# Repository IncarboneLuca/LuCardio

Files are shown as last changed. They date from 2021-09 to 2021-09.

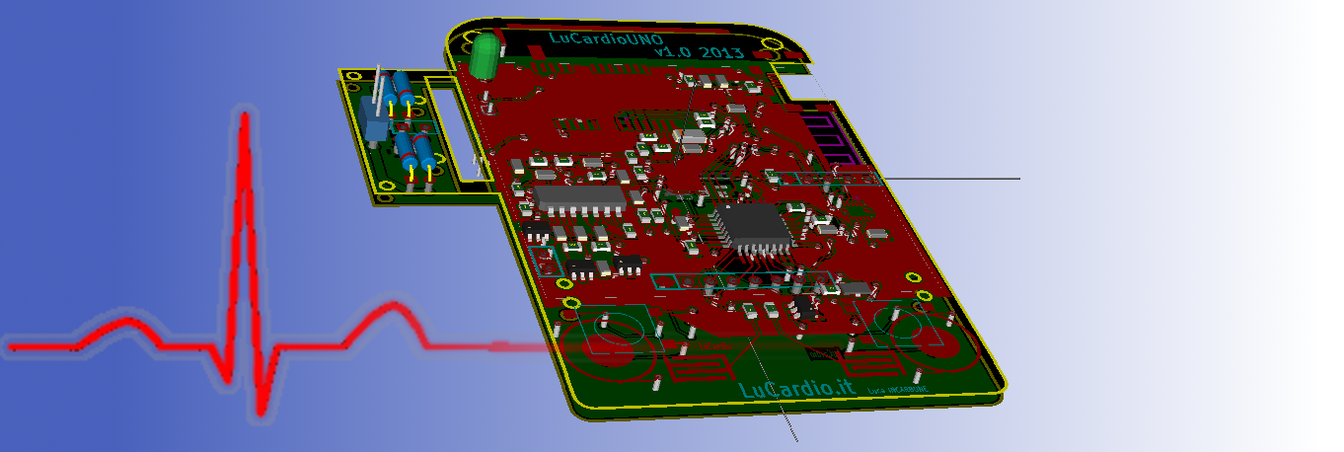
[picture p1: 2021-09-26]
sch/LuCardio_6.png

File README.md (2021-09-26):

# LuCardio
Project started in 2013 with goal to develop a connected SportWatch.
Project phases:
  -Develop the analogic circuit to amplify and filter ECG body signal
  -Analogic interface with the bike to measure the speed
  -PCB layout capacitive button to detect the finger (touch button instead of pushbutton)
  -Develop the Arduino code to test in field and improve the algorithm
  -Develop a second version to run the code on a specific PCB designed (that also include a GNSS receiver and a PCB designed antenna)

Unfortunately the second version was never end because the GNSS receiver chosen had major problem with I2C communication and never work properly. Time and cost to make a second PCB and chose a second GNSS receiver made stop the project

The prototype with ArduinoUNO board was finished, used and tested.

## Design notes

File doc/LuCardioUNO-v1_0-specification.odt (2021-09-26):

# LuCardioUNO v1.0 Specification


# High level Fonctional Specifications

Tag | Specification | min | Typ | Max
1 | GENERAL SPECIFICATION
1.0 | Turn on time in recording mode | 5h | 8h | 10h
1.0.1 | Current consumption in recording mode | | | 150mA
1.0.2 | Battery capacity | 750mA/h | 1500mA/h | -
1.1 | Time to full recharge | | 1h | 3h
1.2 | Fonctional Temperature Range | -10° | - | 40°
1.3 | Backlight duration | | 3 sec
1.4 | Graphic LCD with back-light | LCD NOKIA 5510
1.5 | GPS Antenna (1.575 GHz) | Integrated on PCB
1.6 | Data Connectivity | Bluetooth
1.7 | Power Supply | USB Micro B
2 | ELECTRICAL SPECIFICATION
2.0.0 | Charging voltage | 4.7V | 5V | 6.2V
2.0.1 | Charging current | - | - | 1A
2.1 | System voltage | | 3.3V
3 | PERFORMANCE SPECIFICATION
3.0.0 | Heart Rate Range | 20bpm | - | 220bpm
3.0.1 | Bike Speed Range | 1km/h | - | 100km/h
3.0.2 | Pedal Rate Range | 20 r/min | - | 200 r/min
3.1.1 | Refresh Data Temperature | - | 1 ref/s | -
3.1.2 | Recording Rate | - | 1 rec/s | -
3.1.3 | Refresh LCD output | - | 1 ref/s | -
4 | MECANICAL SPECIFICATION
4.1 | Touch button | | 2
4.2 | Size of PCB (2 Layers) | Battery Size
4.3 | Standard plug I/O (idiot-proof)
4.3.1 | Charging/Pedal/Weel | USB Micro B
4.3.2 | ECG contacts | DX female
4.4.0 | Water proof
5 | HUMAN INTERFACE
5.0 | Menu interactive
5.1 | Screen data
5.2 | Android interface (via Bluetooth)

# LCD data screen specification

## Welcome screen

To be defined

## Recording/Running Mode

Tag | Specification | min | Max | Unit
6.0 | Recording Screen
6.0.0 | Distance measure | 0 | 10'000 | m
| | 10 | 999 | km
6.0.1 | Total distance measure | 0 | 9999999 | km
6.0.2 | Speed bike | 1 | 100 | km/h
6.0.3 | Temperature | | | °C
6.0.4 | Heart Rate (if over print --) | 20 | 220 | bpm
6.0.5 | Battery level | 3.7 | 4.2 | V
6.0.6 | Cronometre | 00:00:00
6.0.7 | Time | 00:00:00
6.0.6 | Pedal rate | 20 | 200 | rot/min
6.1 | Graphic Hysto filling with gliding FIFO (output filling from right to left)
6.1.0 | Deep hystory | 5 | 30 | min
6.1.1 | Horizontal Resolution | 40 | 48 | pixel
6.1.2 | Heart Rate range | 50 | 210 | bpm
6.1.3 | Speed Bike range | 10 | 80 | Km/h
6.1.4 | Heart Rate resolution | 10 | 5 | Bpm
6.1.5 | Speed Bike resolution | 10 | 5 | Km/h
6.1.6 | Distance, Speed,HeartRate
7 | Recording Screen ECG visualization mode
7.0.0 | Heart Rate (if over print --) | 20 | 220 | bpm
7.1.0 | Filling fifo from left to Right
7.2.0 | Resolution | 1/48 | | s
7.3.0 | Distance,Speed,.HeartRate
8 | Recording Screen GPS mode
8.0.1 | Distance measure unit | 0 | 10 km | m
| | 10 km | - | km
8.0.2 | Speed bike | 1 | 100 | km/h
8.0.3 | Temperature | | | °C
8.0.4 | Heart Rate (if over print --) | 20 | 220 | bpm
8.0.5 | Battery level | 3.7 | 4.2 | V
8.0.6 | Pedal rate | 20 | 200 | rot/min
8.1 | GPS info
8.1.0 | Speed | 0.1 | 1854 | km/h
8.1.1 | Latitude | ddmm.mmmm
8.1.2 | Longitude | dddmm.mmmm
8.1.3 | Satellites Used | 0 | 12 | sat
8.1.4 | Altitude | 0 | 18000 | meters
9 | Fonction Menu mode
9.0.0 | Starting record
9.0.1 | Recording Pause
9.0.2 | Stop Recording
9.1.0 | TurnON Bluetooth
9.1.1 | TurnOFF Bluetooth
9.2.0 | The selected function has to be Highlighted
9.3.0 | In the last row the arrow as to be plotted to rappresent the direction of selection correspond to touch buttons

## Fonction Menu Mode

5.0.0 In this mode the user can activate recording stop it and other things. To move up or down there will be

# Buttons

5.0.1 The mode and others functionallitys of LuCardio is driven by 2 touch buttons. The following true table specified the buttons effects.

From State | To STATE (condition below)
| GBTN | | RBTN | | RGBTN
RS | RS-GPS | | RS-ECG | | FMM
RS-ECG | RS | | RS-GPS | | FMM
RS-GPS | RS-ECG | | RS | | FMM
FMM | --- | | --- | | ---

5.0.2 Table describing effect of buttons.

STATE | GBTN | | RBTN | | RGBTN
RS | changeSTATE | | changeSTATE | | changeSTATE
RS-ECG | changeSTATE | | changeSTATE | | changeSTATE
RS-GPS | changeSTATE | | changeSTATE | | changeSTATE
FMM | HighlightedUP | | HighlightedDOWN | | Select

## GBTN, RBTN and RGBTN

4.1.1 The capacitive button needs a basic coding to filter some possible effect with water. For this reason the button it will be considered pushed if two short touch are made.

Tag | specification | min | MAX | unit
4.1.2 | Duration of single touch | 0.1 | 0.5 | s
4.1.3 | Time between two touch | 0.1 | 1 | s
4.1.4 | Number of touch | 2

# Android Interface

To Do

# Data Recording

10.0.0 Data recording as to be recorded on file.csv with ';' as separator (for Excel is the standard column separation for csv importing.

10.0.1 All availeble data will be stored one per second in SD card (to be listed)

10.0.2 File name will be MMDDHHmm.CSV (month day hour minute .csv)

# Function check_switch

## Switch button

This function test both buttons and update the boolean value green_pushed and red_pushed.

This function have to work with two different schematics, first is the simple “switch” one, the capacitor C13, C14, C16, C17 and resistor R11 and R17 are not mounted and R14 and R15 have 0Ohms values.(C16 and C17 are shortcircuited too).

This will be selected by the no definition of BUTTON_touch.

In this case the function has to test the Vbutton pin value with following combination of output:

| RedBTN '0' | RedBTN '1'
GreenBTN '0' | | X
GreenBTN '1' | X

By this way is possible to determinate the update value for red_pushed and green_pushed.

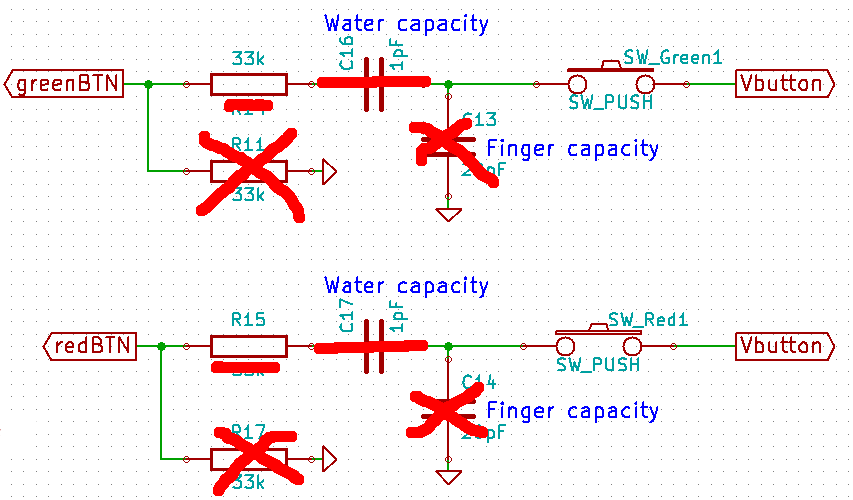
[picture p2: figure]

Or we can set Vbutton to HIGH value and test in the function the input for redBTN and greenBTN. In this case the pulldown resistor R11 and R17 is needed (and pull-down pin set-up in code).

## Touch button

In the second case (BUTTON_touch is defined) the switchs are short-circuited, the resistence R11 and R17 are disconnected. In this function mode the output greenBTN and redBTN have to be driven by this way.

greenBTN | '0' | '1' | '1' | '1' | '0' | '0' | '0'
redBTN | '0' | '0' | '0' | '0' | '0' | '0' | '1'
Vbutton | read value | read value | read value | read value | r.v. | r.v. | r.v.
Treshold reach | no | no | no | yes | no | no | no

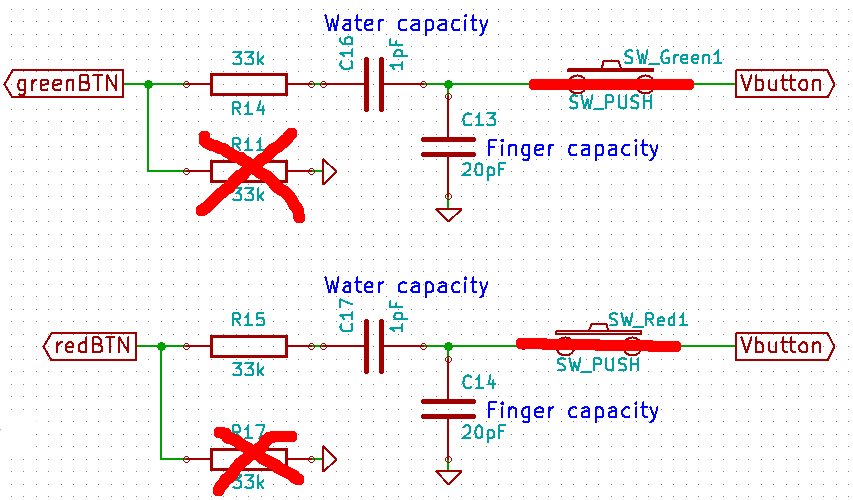
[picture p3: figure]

To found experimentally the clock period to wait from a checcking button to the other (wait for dechanging capacitor and the treshold to get the capacity variation du to finger).

# List of case defined

Name | def | Not def
BUTTON_touch | Touch button are used | Simple switch used
INSTALLATION_PROCEDURE | Factory setup (RTC for ex.) | Normal

LuCardioUNO v1.0 Specification

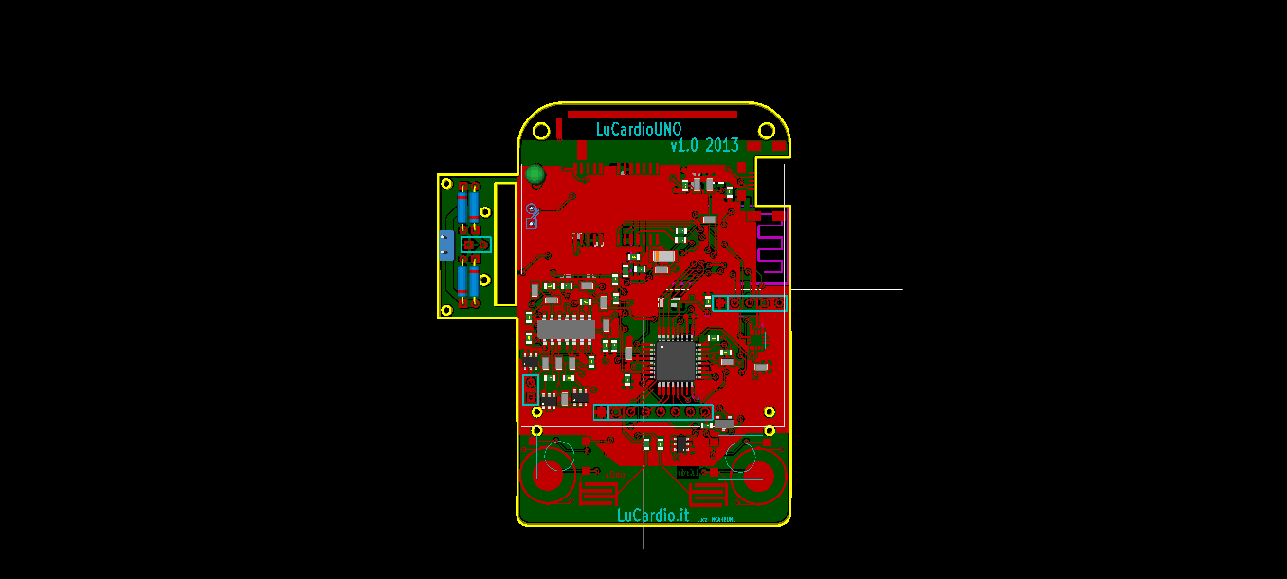
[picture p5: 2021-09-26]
sch/LuCardio_1.png

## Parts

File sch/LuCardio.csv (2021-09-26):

ref | value | Campo1 | Campo2 | Campo3 | Campo4 | Campo5 | Campo6 | Campo7 | Campo8
BT1 | 3.7V Li-ion
C1 | 1uF
C2 | 680nF
C3 | 680nF
C4 | 20pF
C5 | 10pF
C6 | 100uF
C7 | 20pF
C8 | 100nF
C9 | 100nF
C10 | NC
C11 | 680nF
C12 | 1uF
C13 | 20pF
C14 | 20pF
C15 | 100uF
C16 | 1pF
C17 | 1pF
C18 | 20pF
C19 | 100nF
C21 | 1uF
C22 | 10uF
C23 | 470pF
C24 | 1uF
C25 | 1uF
C26 | 100uF
C27 | 100uF
C28 | 10nF
C29 | 10nF
C30 | 1uF
D1 | BAP64-04 | 626-1734
D2 | BAP64-04 | 626-1734
D3 | BAP64-04 | 626-1734
D4 | BAT48 | 687-0852
D5 | redLED
D6 | BAT48 | 687-0852
D7 | DFLZ6V2 | 751-4032
D8 | BBY53 | 752-7899
D9 | BBY53 | 752-7899
D10 | 1N5819 | 708-2197
D12 | 1N5817 | 625-4972
D13 | 1N5817 | 625-4972
D14 | 1N5817 | 625-4972
D15 | 1N5817 | 625-4972
ECG1 | 1
ECG2 | 1
IC1 | ATMEGA328P-A
J1 | USB_2 | 772-6778
L1 | 1µH | 254-7040
L2 | BLM18AG121SN1D | 202-3550
L3 | INDUCTOR
P1 | belt
P2 | TMP100
P3 | S1
P16 | progr
P18 | LCD_NOKIA
Q2 | NDS0610 | 671-1074
Q3 | MMBF170 | 708-2393
R1 | 10k
R2 | 120k
R3 | 10k
R4 | 1M
R5 | 180k
R6 | 390
R7 | 1M
R8 | 1M
R9 | 100k
R10 | 10k
R11 | 33k
R14 | 33k
R15 | 33k
R16 | 2M
R17 | 33k
R18 | NC
R19 | 3.3k
R20 | 1.5k
R21 | 40k
R22 | 200
R23 | 422k
R24 | 422k
R25 | 1050
R26 | 1050
R28 | NC
R29 | 3.3k
SD1 | DM3BT | 738-8818
SW1 | SWITCH_INV | 747-5007
SW_Green1 | SW_PUSH
SW_Red1 | SW_PUSH
U1 | MAX21000
U2 | LT1496
U3 | BLUETOOTH
U4 | LTC1844
U5 | LTC4053EMSE-4.2
U6 | EB-365

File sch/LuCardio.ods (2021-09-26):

ref | value | RS | Reference | farnell | price | check | Campo6 | Campo7 | Campo8
BT1 | 3.7V Li-ion |  | LGIP-400N 1.6Ah |  | 5 | X
C1 | 1uF |  |  |  |  | X
C2 | 680nF |  |  |  |  | X
C3 | 680nF |  |  |  |  | X
C4 | 20pF
C5 | 10pF
C6 | 100uF |  |  |  |  |  | ORDERED
C7 | 20pF
C8 | 100nF
C9 | 100nF
C10 | NC |  |  |  |  | X
C11 | 680nF |  |  |  |  | X
C12 | 1uF |  |  |  |  | X
C13
C14
C15 | 100uF |  |  |  |  |  | ORDERED
C16
C17
C18 | 20pF
C19 | 100nF
C21 | 1uF |  |  |  |  | X
C22 | 10uF |  |  |  |  |  | ORDERED
C23 | 470pF
C24 | 1uF |  |  |  |  | X
C25 | 1uF |  |  |  |  | X
C26 | 100uF |  |  |  |  |  | ORDERED
C27 | 100uF |  |  |  |  |  | ORDERED
C28 | 10nF
C29 | 10nF
C30 | 1uF |  |  |  |  | X
D1 | BAP64-04 | 626-1734
D2 | BAP64-04 | 626-1734
D3 | BAP64-04 | 626-1734
D4 | BAT48 | 687-0852 |  |  |  | X
D5 | redLED |  |  |  |  | X
D6 | BAT48 | 687-0852 |  |  |  | X
D7 | DFLZ6V2 | 751-4032 |  |  |  | X
D8 | BBY53 | 752-7899 |  |  |  | X
D9 | BBY53 | 752-7899 |  |  |  | X
D10 | 1N5819 | 708-2197 |  |  |  | X
D12 | 1N5817 | 625-4972 |  |  |  | X
D13 | 1N5817 | 625-4972 |  |  |  | X
D14 | 1N5817 | 625-4972 |  |  |  | X
D15 | 1N5817 | 625-4972 |  |  |  | X
ECG1 | 1
ECG2 | 1
IC1 | ATMEGA328P-A |  |  |  |  | X
J1 | USB_2 | 772-6778 |  |  |  | X
L1 | 1µH | 254-7040 |  |  |  | X
L2 | BLM18AG121SN1D | 202-3550 |  |  |  | X
L3 | INDUCTOR |  |  |  |  | X
P1 | belt |  |  |  |  | X
P2 | TMP100 |  |  |  |  | X
P3 | S1 |  |  |  |  | X
P16 | progr |  |  |  |  | X
P18 | LCD_NOKIA |  |  |  |  | X
Q2 | NDS0610 | 671-1074 |  |  |  | X
Q3 | MMBF170 | 708-2393 |  |  |  | X
R1 | 10k
R2 | 120k
R3 | 10k
R4 | 1M
R5 | 180k
R6 | 390
R7 | 1M
R8 | 1M
R9 | 100k
R10 | 10k
R11 | 33k
R14 | 33k
R15 | 33k
R16 | 2M
R17 | 33k
R18 | NC
R19 | 3.3k
R20 | 1.5k
R21 | 40k
R22 | 200
R23 | 422k
R24 | 422k
R25 | 1050
R26 | 1050
R28 | NC
R29 | 3.3k
SD1 | DM3BT | 738-8818 |  |  |  |  | ORDERED
SW1 | SWITCH_INV | 747-5007 |  |  |  | X
SW_Green1 | SW_PUSH
SW_Red1 | SW_PUSH
U1 | MAX21000 |  |  |  |  | X
U2 | LT1496 |  |  |  |  | X
U3 | BLUETOOTH |  |  |  |  | X
U4 | LTC1844 |  |  |  |  | X
U5 | LTC4053EMSE-4.2 |  |  |  |  | X
U6 | EB-365 |  |  |  |  | x

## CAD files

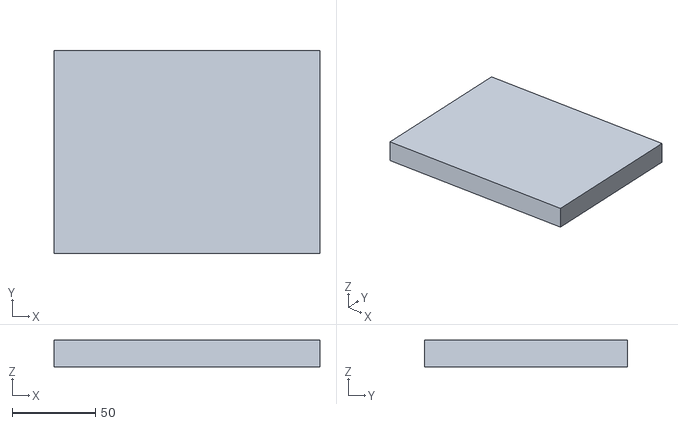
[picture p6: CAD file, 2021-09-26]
sch/eb-356.stl
160.0 x 122.0 x 16.0

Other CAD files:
sch/EB-365.stl

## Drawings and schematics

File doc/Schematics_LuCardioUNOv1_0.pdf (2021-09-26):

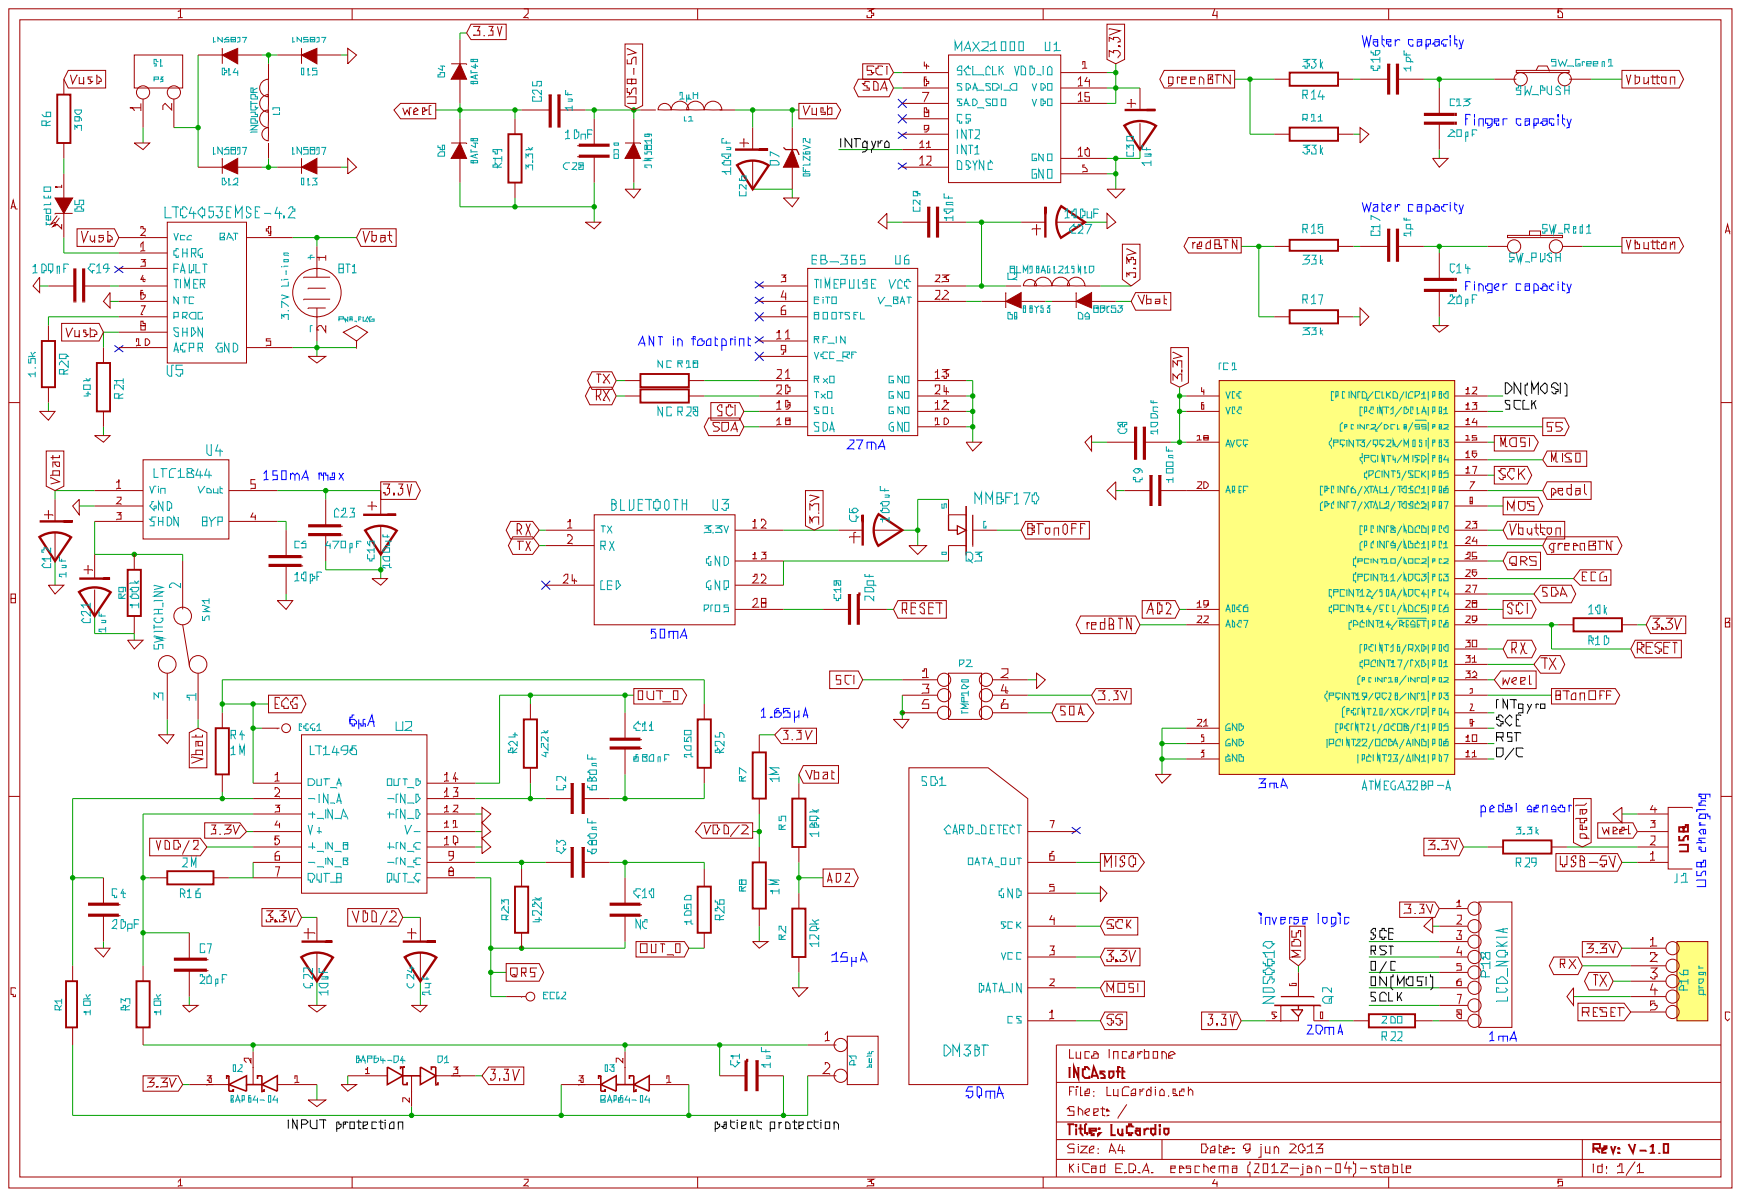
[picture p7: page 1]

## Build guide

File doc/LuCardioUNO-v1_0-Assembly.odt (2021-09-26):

# LuCardioUNO v1.0 Assembly Specification


# Including correction

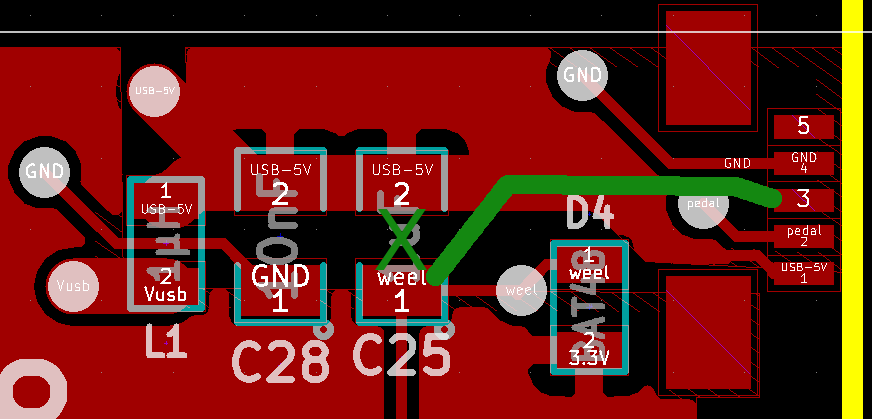
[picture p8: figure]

Weel sensor directly connected

USB PIN 5 have to be connected to GND

D4, D6, C25 not mounted

R19 not mounted if internal pull up resistor is set

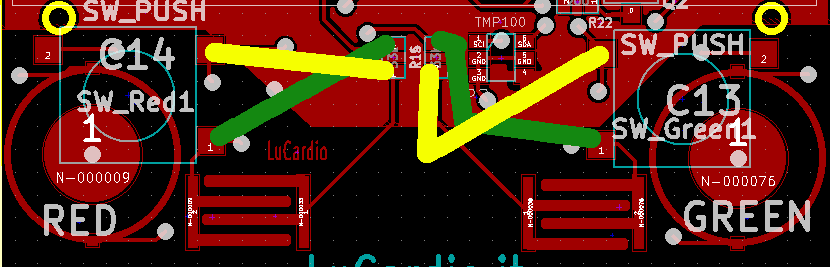
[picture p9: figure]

To use touch button do not mount R14 R15 connect

GSP serial/I2C bridge to add

LuCardioUNO 1.1

-Atmega1284P

-RF connection for belt

-contact-less sensor for HRB

-case for the battery

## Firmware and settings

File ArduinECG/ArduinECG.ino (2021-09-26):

/**
LuCardio UNO
  CardiOpen, project version by Luca 
  ---------------------------------------------------------------
  Author         : Luca Incarbone <luca@incarbone.com>
  First revision : 10/03/2012
  Last revision  : 20/04/2013
---------------------------------------------------------------
---------------------------------------------------------------
  LuCardioUNO v1
      -ATMEGA328P-AU
      -NOKIA LCD display 
      -microSD card
      -ecg detector (LT1496 + R + C)
      -Bluetooth module comunication
      -GPS module EB-356
      -Bike speed detection / charging battery
      -Pedal rate detection
      -1 cell Li-ion battery Power Supply
      -LTC4053 Li-ion charging battery
      -LTC1844 - 3.3V - 150mA 
      -TMP100 temperature sensor
      -Gyroscope MAX21000

Digital	PD0	RX - Bluetoth -(or possible connction to GPS)
	PD1	TX - Bluetoth -(or possible connction to GPS)
	PD2	Wheel sensor interrupt 3.3k pulldown
	PD3	Bluetooth on/off (set pin to pull-down)
	PD4	Interrupt Gyroscope
	PD5	LCD NOKIA - SCE
	PD6	LCD NOKIA - RST
	PD7	LCD NOKIA - D/C
	PB0     LCD NOKIA - DN(MOSI) INPUT GREEN button 1k2 pulldown	- output LEFT button
	PB1     SCLK  INPUT RED button 1k2 pulldown 	- output RIGHT button
	PB2	CS 	SD 
	PB3	MOSI 	SD 
	PB4	MISO 	SD 
	PB5	SCK 	SD 
        PB6     Pedal sensor with 3.3k pull-up
        PB7     Backlight Control (via MOS) (set pin to pull-up)
Analog	PC0	Vbutton - input button (Left/Right) to get finger capacity
	PC1	Green Button
	PC2	ECG filtred 
	PC3     ECG
	PC4	SDA 	- GPS - temperature sensor TMP100 - Gyroscope
	PC5	SCLA 	- GPS - temperature sensor TMP100 - Gyroscope
	PC6	RESET 
        ADC6    Battery check
        ADC7    Red Button

*/
#include "Arduino.h"
#include "Flash.h"
#include "define.h"


//Value read from ADC sensorValue_*
  int sensorValue_ECG;
  int sensorValue_QRS;
  int sensorValue_Vbutton;

//buttons counters
  uint8_t counter_green_but;
  uint16_t counter_red_but;

//Counter to compute speed and distance
  uint8_t bike_loop;//counter time to make loop. 5 to 255 (2 to 113Km/h)  ====> minbikellop = (75*3.6*2.1)/113 = 5
  uint8_t bikeLoop;//to compute value 

//boolean variable
  boolean new_val;//boolean became true with 75Hz interrupt NEW VALUE is available
  boolean red_or_green;//to control alternatively two button
  boolean green_pushed;//boolean true if green is pushed
  boolean red_pushed;//boolean true if red is pushed
  boolean REC; //true if the system is recording
  boolean CRONO; //true if crono is running

//Value for mode selection (changed the display output)
  boolean MODE_1;

//Value changed by serial command change mode ECG/Cardio 
  boolean BT_BPM; //send BPM over bluetooth
  boolean BT_ECG; //send ECG over bluetooth
  boolean ECG; //send ECG over serial
  boolean GET_SD_FILES;//Send the file names find in SD card
  boolean R_FILE;//Receve name from bluetooth
  boolean S_FILE;//Read file in SD card from bluetooth

//Cardio
  uint8_t bpm;//Pulse par minute
  uint16_t lastPik;//Variable to store counter value
  uint16_t counterRR;//Counter to measure the distance between two Rwave R-R
  int ref_1, ref_10;

//Temperature
  int temperature;

//Bike variable
  float distance_float;//m
  uint8_t speedBike;//km/h

//crono variable
  boolean old_refresh;//true each second
  uint8_t state;

//name of file for recording
  char filename[MAX_CHARACTER_FOR_FILE];//"mmddhhmm.csv" month-day-hour-minute
  
//retroillumination
  boolean retroLight;
  uint8_t retroLight_count;

//Variables for communication
  uint8_t reciving_index;
  char com_in;
  
#include "Wire.h"

//Time
  int second,minute, hour;
  DateTime moment;
  DateTime start_crono_time;//time when Start button is pressed
  
#include "SD.h"
  
//SD variable
  boolean SDbegin;
  File logfile;

void timers_setup();
void SetResolution();
int8_t getTemperature();
void get_command_viaRS232();
void image_refresh();
void data_processing();
void button_irq();
void button_check();
void LCD_refresh();
void getFilename(char *);
//int freeRam();
/*
  Setup fonction:
	-setup Serial comunication
	-setup ECG variable default value
	-counter setup
*/

//int main(void){
void setup(){
  //interrupt for weel sensor
  attachInterrupt(0, weel, RISING);
  //variable
  state = 6;
  old_refresh = false;
  retroLight = true;
  BT_BPM = false;
  BT_ECG = false;
  ECG = false;
  R_FILE = false;
  S_FILE = false;
  GET_SD_FILES = false;
  counterRR = 0;
  
  ///// pin ///////
  pinMode(chip_select, OUTPUT);//CS for SPI
  pinMode(pin_Battery, INPUT);//Battery Checker
  pinMode(pin_BackLight, OUTPUT);digitalWrite(pin_BackLight, HIGH);// set pull-up resistor for pin 3, retroillumination via MOS
#ifdef BUTTON_touch
  pinMode(pin_green_but, INPUT);//GREEN button
  pinMode(pin_red_but, INPUT);//RED button
#else 
  pinMode(pin_green_but, OUTPUT);//GREEN button
  pinMode(pin_red_but, OUTPUT);//RED button
#endif
  pinMode(pin_ECG, INPUT);//ECG not filtred
  pinMode(pin_QRS, INPUT);//ECG filtred
  pinMode(pin_Vbutton, INPUT);//Touch button sense

  ////////////  LCD //////////////
 //http://playground.arduino.cc/Code/PCD8544
  ////// I2C ////////
  Wire.begin();        

  //////  Temperature Sensor /////
  SetResolution();

  ////// Serial (bluetooth) //////
  //Serial.begin(2400);//Bluetooth connection
  Serial.begin(115200);//USB debug connection

  lcd.clear();lcd.setCursor(0,0);
  ///////////// Memory SD ////////////
  if (!SD.begin(chip_select)) {
	  lcd<<t_sdfailure;SDbegin = false;
	  return;
  }

  SDbegin = true;

  lcd<<t_sdcarddetected;
  lcd.clear();lcd.setCursor(0,0);

  RTC.begin();
  if (!RTC.isrunning()) {
	lcd<<t_rtcnotrunning;delay(1000);
  }else{
	lcd<<t_rtcisrunning;
  }
  delay(100);
  
#ifdef INSTALLATION_PROCEDURE
  //RTC.adjust(DateTime(__DATE__, __TIME__));
#endif

  /////////////////  Timer Interrupt ////////////////
  cli();//stop interrupts
  
  /////////////////  Timer Interrupt ////////////////
  timers_setup();

  sei();//allow interrupts
//StartUP image

}


/*
  Loop function:
		-get value from ADC0
		-check serial data (to change mode)
		  -In mode ECG send the value and wait 5ms
		  -In mode Cardio fill the buffer, detect the pick and compute the bpm
*/
void loop(){

	    if(!S_FILE){
			get_command_viaRS232();

			data_processing();

			image_refresh(); 

			button_check();
		}else{
			lcd.clear();lcd.setCursor(0,0);lcd<<t_downloading;
			Serial.println(filename);
			logfile = SD.open(filename);
			if(logfile){
				// read from the file until there's nothing else in it:
				while(logfile.available()) {
					Serial.write(logfile.read());
					//lcd.clear();lcd.setCursor(0,0);lcd.print(freeRam());
				}
				// close the file:
				logfile.close();
			}
			S_FILE = false;
		}
}
/*
	________________
	|100000m    REC|	distance
	|25C    BPM    |	temp 	BPM
	|80km/h BPM    |	GPSpeed	BPM
	|80km/h	       |	speed	
	|nSAT  00:00:00|	n SAT	crono
	|bat   00:00:00|	battery	time
	----------------
	________________
	|100000m    REC|	distance
	|25C   80   BPM|	temp 	BPM
	|	       |	Graph
	|______________|		heartrate
	|	       |	Graph
	|	       |		speed
	----------------
	________________
	|100000m    REC|	distance
	|25C   80   BPM|	temp 	BPM
	|	       |	Graph
	|_A_ ______A __|		heart
	|   V       V  |	
	|	       |		
	----------------

*/
void LCD_refresh(){
	String dataString;
#ifndef LCD_V2
        temperature = getTemperature();
        lcd.clear();
        lcd.setCursor(13,0); lcd.print(bpm);
        lcd.setCursor(0,1); lcd.print(speedBike);//lcd.print(speed);
      //lcd.setCursor(2,1); lcd.print("km/h");
      
      lcd.setCursor(4,1); lcd.print(temperature);lcd<<t_celsius;
	  lcd.setCursor(8,1);
	  if(CRONO){  
                    if(moment.second() > start_crono_time.second()){
			second = (moment.second() - start_crono_time.second());
                    }else if(moment.second() == start_crono_time.second()){
                        second = 0;
		    }else{
			second = (60 + moment.second() - start_crono_time.second());
	  	    }
                    if(second==0){
                      if(moment.minute() > start_crono_time.minute()){
			minute = moment.minute() - start_crono_time.minute();
		      }else if(moment.minute()== start_crono_time.minute()){
                        minute = 0;
                      }else{
			minute = 60 + moment.minute() - start_crono_time.minute();
		      }
                    }
                    if(minute==0){
                      if(moment.hour() > start_crono_time.hour()){
			hour = moment.hour() - start_crono_time.hour();
                      }else if(moment.hour() == start_crono_time.hour()){
                        hour = 0;
        	      }else{
			hour = 24 + moment.hour() - start_crono_time.hour();
		      }
                    }
		lcd.print(hour);
		lcd.print(t_dotdot[0]);
		lcd.print(minute);
		lcd.print(t_dot[0]);
		lcd.print(second);
		
	  }else{
	        dataString = String(moment.hour());
		dataString += t_dotdot[0];
		dataString += String(moment.minute());
		dataString += t_dot[0];
		dataString += String(moment.second());
		lcd.print(dataString);
	  }		  
	  
	  int sensorValue_battery;//A2
	  sensorValue_battery = analogRead(pin_Battery);
          //lcd.setCursor(8,0);lcd.print(sensorValue_battery);
      if(sensorValue_battery<limit_battery){
        lcd.setCursor(8,0);lcd<<t_lowbattery;
      }
	  lcd.setCursor(0,0);lcd<<t_empty;
      if (distance_float > 10000.0){
		lcd.setCursor(0,0); lcd.print((int)(distance_float/1000));lcd<<t_kilometer;
      }else{
		lcd.setCursor(0,0); lcd.print((int)distance_float);lcd<<t_meter;
      }
#endif
}

#ifdef BUTTON_touch
void button_check(){
	if(digitalRead(pin_green_but)){
		counter_green_but++;
	}else{
		counter_green_but = 0;
	}
	if(digitalRead(pin_red_but)){
		counter_red_but++;
	}else{
		counter_red_but =0;
	}
	if((counter_green_but==255) & (state!=crono_RUN_cardio_REC)){
		retroLight=true;
		state=crono_START_pressed;
		counter_green_but =0;
	}else if(counter_green_but==255){
		retroLight=true;
		counter_green_but =0;
	}
	if((counter_red_but==(65535/2)) & (state==crono_RUN_cardio_REC)){
		state=crono_STOP_RECORDING;
		counter_red_but =0;
	}

}
#else
void button_check(){
	//if the values  are 0 then we are ready to make new test
	if(red_but == 0 & green_but == 0){
		if(red_or_green){
			counter_red_but = 0;
			green_but = 1;
		}else{
			counter_red_but = 0;
			red_but = 1;
		}
	}

	if(red_pushed & state==crono_RUN_cardio_REC){
		//stop recording
		state=crono_STOP_RECORDING;
		red_but = 0;
		//reset counter variable, used to wait unload capacity. two time longer to get it close to zero volt
	for(counter_red_but=counter_red_but*2;counter_red_but>0;counter_red_but--){}
}

if(green_pushed & state!=crono_RUN_cardio_REC){
	//turn on the backlight
	retroLight=true;
	//change state to start crono mode
	state=crono_START_pressed;
	green_but = 0;
	//reset counter variable, used to wait unload capacity. two time longer to get it close to zero volt
for(counter_red_but=counter_red_but*2;counter_red_but>0;counter_red_but--){}
  }else if(green_pushed){
	//turn on the backlight
    retroLight=true;
    green_but = 0;
	//reset counter variable, used to wait unload capacity. two time longer to get it close to zero volt
    for(counter_red_but=counter_red_but*2;counter_red_but>0;counter_red_but--){}
  }

}

void button_irq(){
  counter_red_but++;
//get value
  step_mes = analogRead(pin_Vbutton);  i_step_mes = (int)step_mes;
//test value 
  if(i_step_mes > TRESHOLD){
	//evaluation time constant
    if(counter_red_but > TAU){
	//select original pullup signal
      if(red_or_green){
        green_pushed = true;
      }else{
        red_pushed = true;
      }  
	//time constant is lower than limit = no finger
    }else{
      green_pushed = false;
      red_pushed = false;
    }
	//get treshold we change button test pullup 
    red_or_green = not red_or_green;
  }
}
#endif 

void data_processing(){
  /************************************************************************************/
  //Send the value to IHM in mode ECG
  /*
    ECG  active simple ECG cube send (stand alone ECG)
    BPM  Active cardio mode
      BT_BPM send via Bluetooth the heart-rate
      BT_ECG send via Bluetooth the ECG
  */
  if(new_val){
    if(ECG)Serial.println(sensorValue_QRS);//mode ECG
    if(BT_BPM) Serial.println(int(bpm));//send via Bluetooth data
#ifndef BUTTON_touch
    if(ECGnotFiltred) Serial.println(sensorValue_ECG); //for Bluetooth future module
#endif	
	new_val=false;
  }    
  if(GET_SD_FILES){
	// set up variables using the SD utility library functions:
	Sd2Card card;
	SdVolume volume;
	SdFile root;
	int chipSelect = chip_select;
	card.init(SPI_HALF_SPEED, chipSelect);
	volume.init(card);
	root.openRoot(volume);
	// list all files in the card with date and size
	root.ls(LS_R);	
	GET_SD_FILES = false;		
  }
}
void getFilename(char *filename){
	//int year = now.year(); 
	int month = moment.month(); 
	int day = moment.day(); 
	int hour = moment.hour(); 
	int minute = moment.minute();
	/*filename[0] = '2';
	filename[1] = '0';
	filename[2] = year%10 + '0';
	filename[3] = year%10 + '0';*/
	filename[0] = month/10 + '0';
	filename[1] = month%10 + '0';
	filename[2] = day/10 + '0';
	filename[3] = day%10 + '0';
	filename[4] = hour/10 + '0';
	filename[5] = hour%10 + '0';
	filename[6] = minute/10 + '0';
	filename[7] = minute%10 + '0';
	filename[8] = '.';
	filename[9] = 'C';
	filename[10] = 'S';
	filename[11] = 'V';
	return;
}

void image_refresh(){
	String dataString;
  /************************************************************************************/
  //manage the refresh of LCD display
  if(old_refresh){
        //ECG bpm
        uint8_t bpm_tmp = (250*60/(lastPik));// =15000/30 =15000/210
        if(!CRONO){
          bpm = bpm_tmp;
        }else if((bpm_tmp < (bpm-40))&(bpm_tmp > (bpm+40))){
          bpm = bpm;
        }else if((bpm_tmp < (bpm-20))&(bpm_tmp > (bpm+20))){
          bpm = (bpm + bpm_tmp)/2;
        }else{
          bpm = bpm_tmp;
        }
	moment = RTC.now();
	float ruota_x_bike_loop;
        ruota_x_bike_loop = ((weel_circonference*75)/bikeLoop);
        speedBike = ruota_x_bike_loop*3.6;
        if(speedBike < 3)speedBike = 0;

        switch (state) {
          case crono_RUN:
		LCD_refresh();
                break;
          case crono_START_pressed:
#ifndef LCD_V2
		lcd.clear();
#endif
                //NAME date and hour using RTC
                getFilename(filename);
		//single name with start time!!
		logfile = SD.open(filename, FILE_WRITE);
                if(logfile){
	                logfile<<t_beginoffile;
                        logfile.println(" ");
	                logfile.close();
#ifndef LCD_V2
                        lcd.setCursor(0,0); lcd.print(filename);
#endif
                }
		start_crono_time = moment;
                distance_float = 0;
                second = 0;minute = 0; hour= 0;
                CRONO = true;//start crono
                REC = true;//start recording
                state = crono_RUN_cardio_REC;
				break;
          case crono_RUN_cardio_REC:
                LCD_refresh();
#ifndef LCD_V2
		lcd.setCursor(11,0);lcd<<t_r;
#endif
                break;
          case crono_STOP_RECORDING:
                REC = false; //stop recording
                CRONO = false; //stop recording
                retroLight =true;
#ifndef LCD_V2
		lcd.clear();
                lcd.setCursor(0,0); lcd<<t_filesavedon;
      		lcd.setCursor(0,1); lcd.print(filename);
#endif
		state = 6;
                update_total_km((int)distance_float);
		delay(50);
                          break;
           default:                
                LCD_refresh();
                break; 
        }
        //back-light stay for 3 seconds
        if(retroLight){
          if(retroLight_count<3){
            retroLight_count++;
          }else{
            retroLight_count = 0;
            retroLight =false;
          }
          digitalWrite(pin_BackLight, HIGH);
        }else{
          digitalWrite(pin_BackLight, LOW);
        }
        if(REC & SDbegin){

          dataString = String(int(bpm));
          dataString += t_dotcomma[0]; 
          dataString += String(speedBike);
	  dataString += t_dotcomma[0]; 
	  dataString += String((int)distance_float);
	  dataString += t_dotcomma[0]; 
          dataString += String(temperature);
       	  dataString += t_dotcomma[0]; 
          dataString += String(moment.hour());
       	  dataString += t_dot[0]; 
          dataString += String(moment.minute());       	  
          dataString += t_dot[0]; 
          dataString += String(moment.second());
	  logfile = SD.open(filename, FILE_WRITE);
          if(logfile){
            logfile.println(dataString);                
            logfile.close();
          }
        }          
     	old_refresh = false;
  }
}
void get_command_viaRS232(){
	//get command from serial port (if any)
	if (Serial.available() > 0) {
		if(!R_FILE){
			// read the incoming byte:
			com_in = Serial.read();
			switch (com_in){
				
				case 'E':
				ECG=true;
				break;
				
				case 'G':
				GET_SD_FILES = true;
				break;
				
				case 'B':
				BT_ECG=true;
				break;
				
				case 'Y':
				BT_BPM=true;
				break;
				
				case 'R':
				BT_BPM=false;BT_ECG=false;ECG=false;R_FILE=true;reciving_index=0;
				break;
				
				case 'D':
				SD.remove(filename);
				break;
				
				default:
				BT_BPM=false;BT_ECG=false;ECG=false;R_FILE=false;S_FILE=false;GET_SD_FILES=false;//cardio mode is the default mode
			}
		}else{
			while ((reciving_index < MAX_CHARACTER_FOR_FILE) & (filename[reciving_index-1] != 'V')){
				if(Serial.available() > 0){
				 char inChar = Serial.read(); // Read a character
				 filename[reciving_index] = inChar; // Store it
				 reciving_index++; // Increment where to write next
				}				 
			}	
			filename[reciving_index] = '\0';
			R_FILE=false;
			S_FILE=true;
		}
	}
}

int8_t getTemperature(){
  Wire.requestFrom(TMP101,2);
  byte MSB = Wire.read();
  byte LSB = Wire.read();
 
  int TemperatureSum = ((MSB << 8) | LSB) >> 4;
 
  float celsius = TemperatureSum*0.0625;
  return (int8_t)celsius;
}
 
void SetResolution(){
  Wire.beginTransmission(TMP101);
  Wire.write(B00000001); //addresses the configuration register
  Wire.write(((ResolutionBits-9) << 5)); //writes the resolution bits
  Wire.endTransmission();
 
  Wire.beginTransmission(TMP101); //resets to reading the temperature
  Wire.write((byte)0x00);
  Wire.endTransmission();
}

uint16_t get_total_km(){
  Wire.beginTransmission(DS1307_ADDRESS);
  Wire.write(8);	
  Wire.endTransmission();

  Wire.requestFrom(DS1307_ADDRESS, 2);
  uint16_t total = Wire.read();
  total = total * 256;
  total = Wire.read() | total;
  Wire.endTransmission();
return total;
}

void update_total_km(int partial){
  Wire.beginTransmission(DS1307_ADDRESS);
  Wire.write(8);	
  Wire.endTransmission();

  Wire.requestFrom(DS1307_ADDRESS, 2);
  uint16_t total = Wire.read();
  total = total * 256;
  total = Wire.read() | total;
  Wire.endTransmission();
  total =  partial + total;
  
  uint8_t total_MSB = total/256;
  uint8_t total_LSB = total - (total_MSB*256);
  Wire.beginTransmission(DS1307_ADDRESS);
  Wire.write(8);
  Wire.write(total_MSB);
  Wire.write(total_LSB);
  Wire.endTransmission();
}

void timers_setup(){
	//set timer0 interrupt at 250Hz
	TCCR0A = 0;// set entire TCCR2A register to 0
	TCCR0B = 0;// same for TCCR2B
	TCNT0  = 0;//initialize counter value to 0
	// set compare match register for 250Hz increments
	OCR0A = 60;// = (16*10^6) / (250*1024) - 1 (must be <61)
	// turn on CTC mode
	TCCR0A |= (1 << WGM01);
	// Set CS12 and CS10 bits for 1024 prescaler
	TCCR0B |= (1 << CS12) | (1 << CS10);
	// enable timer compare interrupt
	TIMSK0 |= (1 << OCIE0A);

	//set timer1 interrupt at 1Hz
	TCCR1A = 0;// set entire TCCR1A register to 0
	TCCR1B = 0;// same for TCCR1B
	TCNT1  = 0;//initialize counter value to 0
	// set compare match register for 1hz increments
	OCR1A = 15624;// = (16*10^6) / (1*1024) - 1 (must be <15625)
	// turn on CTC mode
	TCCR1B |= (1 << WGM12);
	// Set CS12 and CS10 bits for 1024 prescaler
	TCCR1B |= (1 << CS12) | (1 << CS10);
	// enable timer compare interrupt
	TIMSK1 |= (1 << OCIE1A);

	//set timer2 interrupt at 75Hz
	TCCR2A = 0;// set entire TCCR2A register to 0
	TCCR2B = 0;// same for TCCR2B
	TCNT2  = 0;//initialize counter value to 0
	// set compare match register for 22hz increments
	OCR2A = 207;// = (16*10^6) / (75*1024) - 1 (must be <207)
	// turn on CTC mode
	TCCR2A |= (1 << WGM21);
	// Set CS11 bit for 1024 prescaler
	TCCR2B |= (1 << CS20)|(1 << CS21)|(1 << CS22);
	// enable timer compare interrupt
	TIMSK2 |= (1 << OCIE2A);
}

ISR(TIMER0_COMPA_vect){//timer0 interrupt 250Hz 
  //get value from ADC (ECG)
#ifdef BUTTON_touch
	sensorValue_QRS = analogRead(pin_QRS);
#else
	sensorValue_ECG = analogRead(pin_ECG);
#endif
	counterRR++;//500:71   
    //(250*60/(lastPik)); =15000/30 =15000/210  ===> 500:71
#ifndef ECG_not_filtred
        ref_1 = (sensorValue_QRS/2) + (ref_10/2);
        ref_10 = sensorValue_QRS;
#else
        ref_1 = (sensorValue_ECG/2) + (ref_10/2);
        ref_10 = sensorValue_ECG;
#endif
        if((ref_1 > 9)&(counterRR>71)&(counterRR<500)){
		lastPik = counterRR;
		counterRR=0;
	}else if(counterRR>700){//end of RS wave detection
                counterRR=0;
    	}
        

//Serial.println(ref_1);
}

void weel(){
	if(bike_loop > 4){
		bikeLoop = bike_loop;
		distance_float = distance_float + weel_circonference;
		bike_loop = 0;
	}
}

ISR(TIMER1_COMPA_vect){//timer1 interrupt 1Hz 
  old_refresh = true;
}
  
ISR(TIMER2_COMPA_vect){//timer1 interrupt 75Hz 
	if(bike_loop<255){
          bike_loop++;
        }else{ 
          bikeLoop = bike_loop;
        }
	new_val = true;
#ifndef BUTTON_touch
	button_irq();
#endif
}
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

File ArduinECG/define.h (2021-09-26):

#define crono_STOP_RECORDING   5
#define crono_RUN_cardio_REC_start  4
#define crono_RUN_cardio_REC  3
#define crono_START_pressed  2
#define crono_RUN  1
//Treshold to get pick in "RSwave" search
#define alpha 5
#define beta 3
#define treshold 30
#define tmpAddress 0b1001011
#define ResolutionBits 8
#define chip_select 10
#define weel_circonference 2.1

//SD library constant dipendency
#define MAX_CHARACTER_FOR_FILE 13

//button and pin
#define 1
#define 2
#define 3
#define 4
#define 5
#define 6
#define 7
#define  8
#define  9
#define pin_Vbutton A0
#define pin_green_but A1
#define pin_QRS A2
#define pin_ECG A3 
#define pin_I2C_SDA A4
#define pin_I2C_SCL A5
#define pin_Battery A6
#define pin_red_but A7

//constants
//treshold for Low Battery indicator --->  7V * 1.2k/3k = 2.8 --->   1023*2.8/5 = 572
#define limit_battery 800 
//#define secDot 0.0034375 //Constant to compute the "bpm"
#define size_pipe_ecg 14
#define half_size_pipe_ecg 7
#define TRESHOLD 3
#define TAU 10 

//ADD0 Vdd ADD1 GND
#define TMP101 0b1001000

//Distance between two analysed dots in "RSwave" search
#define delta 5 

#define BUTTON_touch
//#define BLUETOOTH
#define TERMOMETRE

#define RAMSIZE 2048 //you can probably get this from another define somewhere
//#define INSTALLATION_PROCEDURE 1

FLASH_STRING(t_lucardio, "LuCardio 2013 ")
FLASH_STRING(t_sdfailure, "SD card FAILURE")
FLASH_STRING(t_sdcarddetected, "SD card detected")
FLASH_STRING(t_rtcnotrunning, "RTC NOT running!")
FLASH_STRING(t_rtcisrunning, "RTC is running!")
FLASH_STRING(t_lucardiotwo, "->>>>      ")
FLASH_STRING(t_downloading, "downloading")
FLASH_STRING(t_lowbattery, "LB")
FLASH_STRING(t_kilometer, "km")
FLASH_STRING(t_meter, "m")
FLASH_STRING(t_speedbike, "speedBike")
FLASH_STRING(t_bpm, "bpm")
FLASH_STRING(t_distance_float,"distance_float")
FLASH_STRING(t_temperature, "temperature")
FLASH_STRING(t_r, "R")
FLASH_STRING(t_filesavedon,"File Saved on:")
FLASH_STRING(t_minus,"-")
FLASH_STRING(t_celsius, "C")
FLASH_STRING(t_beginoffile, "bpm;speed bike;distance float;temperature;time")
FLASH_STRING(t_empty,"    ")
FLASH_STRING(t_dotcomma,";")
FLASH_STRING(t_dotdot,":")
FLASH_STRING(t_dot,".")
